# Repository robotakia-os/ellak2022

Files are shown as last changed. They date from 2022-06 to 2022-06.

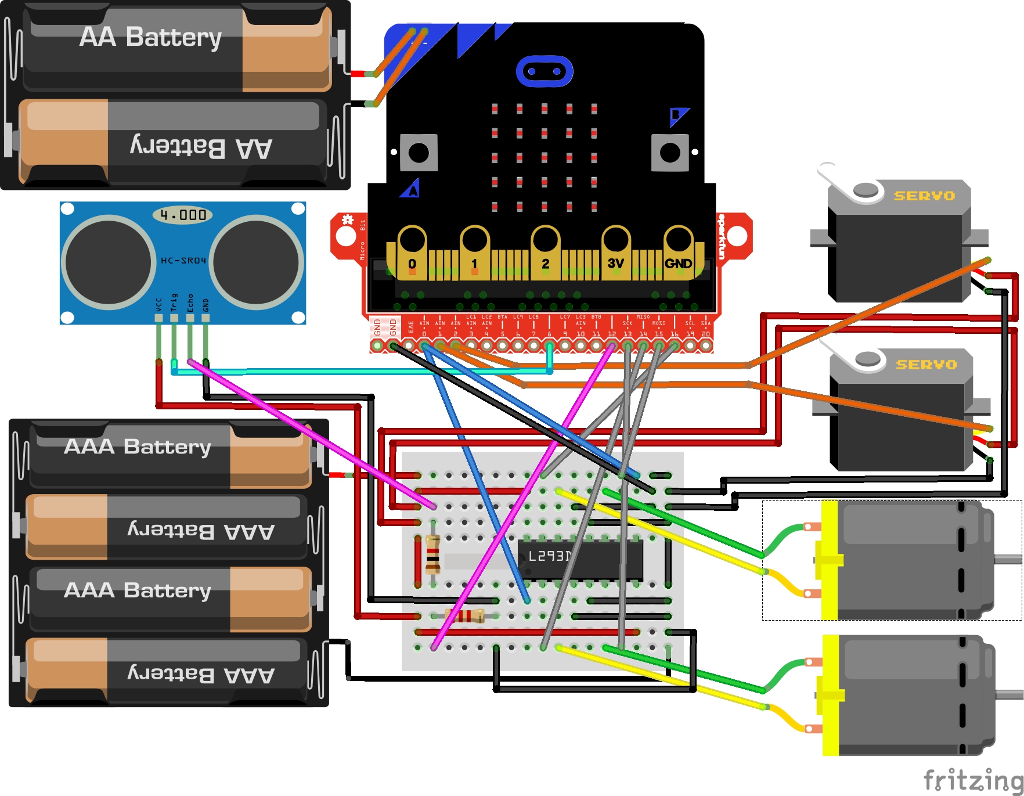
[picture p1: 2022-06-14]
Συνδεσμολογία/robot.jpg

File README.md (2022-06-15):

# ellak2022

4ος Πανελλήνιος Διαγωνισμός Ανοιχτών Τεχνολογιών στην Εκπαίδευση (2022)

Η αλματώδης εξέλιξη της τεχνολογίας τις τελευταίες δεκαετίες έχει αυξήσει τη ζήτηση πολύτιμων μεταλλευμάτων και έχει δημιουργήσει την ανάγκη αξιοποίησης πόρων που παλιότερα έμεναν ανεκμετάλλευτοι. Παρόλα αυτά, η τεχνολογική εξέλιξη της ανθρωπότητας δεν πρέπει να συνοδεύεται από ταυτόχρονη καταστροφή του πλανήτη μας. Η μελλοντική εξόρυξη νέων πόρων και υλικών δεν θα πρέπει να συντελείται σε βάρος των ζώων, των φυτών και των ανθρώπων. Η ζώνη των αστεροειδών αποτελεί μία θεωρητικά ανεξάντλητη πηγή αγαθών που θα μπορούσε δυνητικά να αξιοποιηθεί από την ανθρωπότητα. 

Με την παρούσα εργασία μας, επιχειρήσαμε να αναπαραστήσουμε σε μία μακέτα την προσεδάφιση, την εξερεύνηση και τη συλλογή μεταλλευμάτων από ένα ρομποτικό όχημα σε έναν αστεροειδή. Για τον σκοπό αυτό, δημιουργήσαμε και συναρμολογήσαμε τα μηχανικά μέρη του ρομπότ και υλοποιήσαμε τη συνδεσμολογία των κινητήρων, των αισθητήρων και πλήθος άλλων ηλεκτρονικών εξαρτημάτων. Για την περιήγηση και τον έλεγχο του βραχίονα του ρομπότ χρησιμοποιείται το πληκτρολόγιο του υπολογιστή και η ανίχνευση των πολύτιμων μεταλλευμάτων πραγματοποιείται με τη βοήθεια της Τεχνητής Νοημοσύνης.

Η ιστοσελίδα του έργου: https://openedtech.ellak.gr/robotics2022/robotakia-open-source-na-kitate-pano/

Βίντεο παρουσίασης του έργου: https://www.youtube.com/watch?v=jcSa2XPJCZg

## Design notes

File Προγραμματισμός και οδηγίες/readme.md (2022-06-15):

Το πρόγραμμα robot_program_with_motor_driver είναι παρόμοιο με το robot_program, όμως έχουν τροποποιηθεί τα pin ενεργοποίησης των κινητήρων, για να είναι συμβατό με το Motor Driver Breakout της Waveshare σε περίπτωση που χρησιμοποιηθεί αυτό για την υλοποίηση του κυκλώματος αντί της H-Bridge L293D.

Το αρχείο microbit-mbit-more-v2-0_2_4 είναι απαραίτητο για να προγραμματιστεί το Microbit με τον editor Stretch3 (περισσότερες λεπτομέριες στο pdf "Επεξήγηση προγράμματος").

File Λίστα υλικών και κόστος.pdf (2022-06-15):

- Το συνολικό κόστος υλοποίησης του έργου δεν ξεπερνά τα 60€, συμπεριλαμβανομένων των δευτερευόντων υλικών που χρησιμοποιήθηκαν (σπρέι, μπαταρίες, θερμόκολλα κ.ά.).
- Είτε χρησιμοποιήσουμε για τον έλεγχο των κινητήρων το τσιπάκι H-Bridge L293D (0,6€) είτε την επέκταση Motor Driver Breakout της Waveshare (14,9€) προκύπτει τελικά ένα παραπλήσιο συνολικό κόστος, καθώς μπορεί η σκέτη “γέφυρα” να κοστίζει ελάχιστα, απαιτεί όμως ένα σημαντικό αριθμό περιφερειακών εξαρτημάτων για να υλοποιηθεί το τελικό κύκλωμα.
- Για τον υπολογισμό του κόστους του τυπωμένου ρομπότ προσθέσαμε τα γραμμάρια του PLA που απαιτούνταν για το κάθε κομμάτι. Για τη μάζα του κάθε κομματιού λάβαμε υπόψη την εκτίμηση των γραμμαρίων από το λογισμικό του 3d printer (Prusa Mini). Έτσι προέκυψαν συνολικά 383g και με δεδομένο ότι η τιμή για το 1kg PLA νήματος είναι 20,5€ (τιμή Hellas Digital), προκύπτει ότι το ρομπότ κόστισε περίπου 7,9€ σε PLA.
- Για το χαρτόνι της μακέτας χρησιμοποιήσαμε ένα μεγάλο κομμάτι από κάποια συσκευασία και διαθέταμε ήδη μία απλή USB κάμερα και 3d printer.

Λίστα υλικών και κόστος με H-Bridge L293D

- Νήμα PLA 383g: 7,9€
- Microbit v2: 18,9€
- 2 x Servo Micro: 7,2€
- 2 x DC Gear Motor (με καλώδια): 3,6€
- Μπαταριοθήκη 4xΑΑΑ (με διακόπτη): 1,0€
- Μπαταριοθήκη 2xΑΑΑ (με διακόπτη): 0,9€
- HC-SR04 Ultrasonic sensor: 1,5€
- H-Bridge L293D: 0,6€
- Edge Connector Breakout Board (pre-built): 6,0€
- Mini Breadboard (170 holes): 1,6€
- Καλώδια και αντιστάτες: 2€

Σύνολο: 51,2€

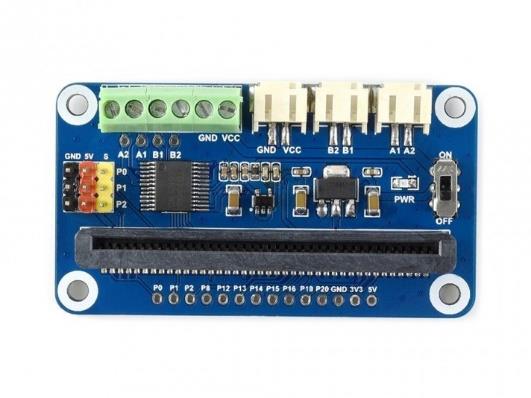
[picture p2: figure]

Λίστα υλικών και κόστος με Motor Driver Breakout

- Νήμα PLA 383g: 7,9€
- Microbit v2: 18,9€
- 2 x Servo Micro: 7,2€
- 2 x DC Gear Motor (με καλώδια): 3,6€
- Μπαταριοθήκη 4xΑΑΑ (με διακόπτη): 1,0€
- Waveshare Motor Driver Breakout: 14,9€
- Pin Header (1x40): 0,1€

Σύνολο: 53,6€

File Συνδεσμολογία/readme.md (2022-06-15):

Για την καταγραφή της συνδεσμολογίας χρησιμοποιήθηκε το λογισμικό Fritzing.

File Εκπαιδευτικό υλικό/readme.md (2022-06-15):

Εκπαιδευτικό υλικό σχετικό με τους αστεροειδείς και τη δυνατότητα εξορύξεων σε αυτούς, με σκοπό την εξοικονόμηση των πόρων και των υλικών του πλανήτη μας.

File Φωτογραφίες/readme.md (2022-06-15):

Φωτογραφίες υψηλής ανάλυσης που λήφθηκαν κατά τη διάρκεια των εργαστηρίων και λεπτομερείς φωτογραφίες του ρομπότ.

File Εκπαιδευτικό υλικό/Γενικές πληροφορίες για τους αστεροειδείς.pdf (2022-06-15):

Γενικές πληροφορίες για τους αστεροειδείς

- Οι αστεροειδείς είναι μικρά σώματα του Ηλιακού συστήματος, που είναι σε τροχιά γύρω από τον Ήλιο. Η συντριπτική πλειονότητα των αστεροειδών είναι συγκεντρωμένη σε δύο Ζώνες: στην Κύρια Ζώνη Αστεροειδών (ανάμεσα στον Άρη και στον Δία) και στη Ζώνη του Κάιπερ (Μεταποσειδώνια Αντικείμενα). Υπολογίζεται ότι υπάρχουν εκατομμύρια αστεροειδείς στο Ηλιακό σύστημα. Το μέγεθός τους ποικίλλει από λίγες δεκάδες μέτρα μέχρι εκατοντάδες χιλιόμετρα. Με πολύ απλά λόγια, μπορούμε να περιγράψουμε τους αστεροειδείς σαν τεράστιους βράχους σε τροχιά γύρω από τον Ήλιο. Κάποιοι από τους αστεροειδείς έχουν και οι ίδιοι μικρούς δορυφόρους, ενώ έχουν ανακαλυφθεί και κάποια τριπλά συστήματα. Οι αστεροειδείς της Κύριας Ζώνης Αστεροειδών θεωρούνται κατάλοιπα από το σχηματισμό του Ηλιακού συστήματος και ήταν το υλικό για έναν μικρό πλανήτη, που όμως δεν σχηματίστηκε ποτέ λόγω της επίδρασης της βαρύτητας του Δία.

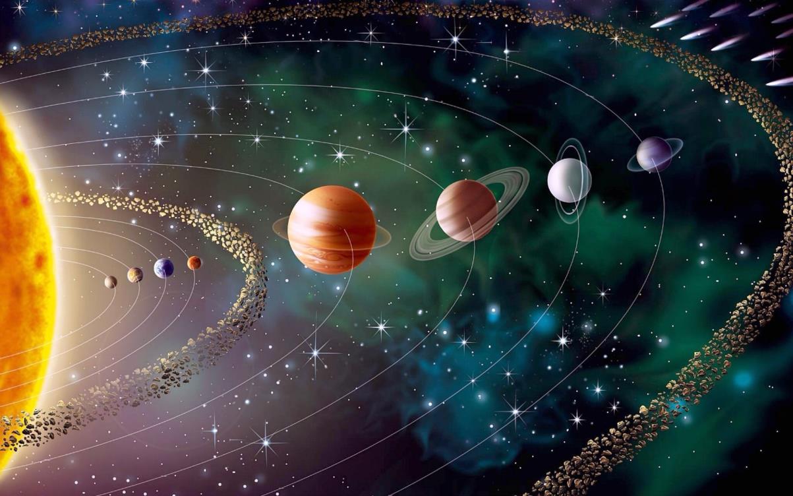
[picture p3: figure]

- Τα σχήματα των αστεροειδών χωρίζονται κυρίως σε δύο οικογένειες. Μερικά είναι σχεδόν απόλυτα σφαιρικά, όπως η Υγεία και η Δήμητρα, ενώ άλλα έχουν περίεργα «μακρόστενα» σχήματα, των οποίων η αδιαμφισβήτητη βασίλισσά τους είναι η Κλεοπάτρα, ο αστεροειδής με σχήμα «κοκκαλοσκύλου». Συνδυάζοντας τα σχήματα των αστεροειδών με πληροφορίες για τις μάζες τους, οι αστρονόμοι διαπίστωσαν ότι οι πυκνότητές τους ποικίλουν. Η μικρότερη πυκνότητα των αστεροειδών, όπως π.χ. των Lamberta και Sylvia, φτάνει στα 1,3 γραμμάρια ανά κυβικό εκατοστό, περίπου όση πυκνότητα του κάρβουνου. Την μεγαλύτερη πυκνότητα έχουν οι αστεροειδείς Ψυχή και Καλλιόπη, 3,9 και 4,4 γραμμάρια ανά κυβικό εκατοστό, αντίστοιχα (συγκριτικά η πυκνότητα του διαμαντιού είναι 3,5 γραμμάρια ανά κυβικό εκατοστό). Αυτές οι μεγάλες διαφορές πυκνότητας δείχνουν ότι η σύνθεση των αστεροειδών ποικίλλει σημαντικά, δίνοντας στους αστρονόμους σημαντικές ενδείξεις για την προέλευσή τους. Συγκεκριμένα, αναδεικνύεται η θεωρία ότι οι λιγότερο πυκνοί αστεροειδείς σχηματίστηκαν σε απομακρυσμένες περιοχές πέρα από την τροχιά του Ποσειδώνα και μετανάστευσαν στη σημερινή τους θέση.
- Μετά το 1990 το ενδιαφέρον για τους αστεροειδείς αναθερμάνθηκε, κυρίως λόγω της ανησυχίας για μια πιθανή σύγκρουση ενός από αυτούς με τη Γη, πράγμα που θα είχε καταστροφικές συνέπειες. Έτσι ξεκίνησε μια προσπάθεια για εντοπισμό, καταγραφή και υπολογισμό της τροχιάς όσο το

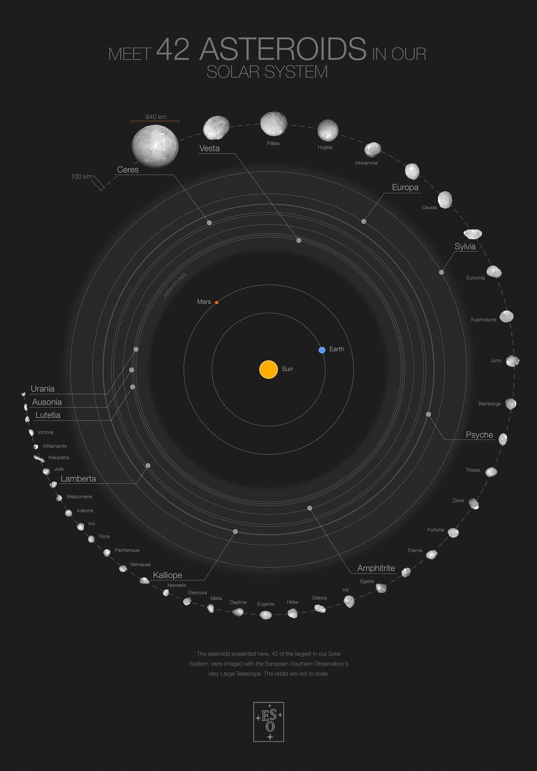
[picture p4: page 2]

δυνατόν περισσότερων αστεροειδών, τόσο με συσκευές σε τροχιά όσο και με γήινα τηλεσκόπια. Η έρευνα αυτή έχει μέχρι στιγμής χαρτογραφήσει εκατοντάδες χιλιάδες αστεροειδείς. Από το 2025 οι αστρονόμοι θα είναι σε θέση να απεικονίσουν περισσότερους αστεροειδείς με λεπτομέρειες με την ολοκλήρωση της κατασκευής του μεγαλύτερου και ισχυρότερου από το τηλεσκοπίου VLT, του τηλεσκοπίου Extremely Large Telescope (ELT).

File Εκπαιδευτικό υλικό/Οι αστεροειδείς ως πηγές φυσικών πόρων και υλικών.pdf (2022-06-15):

Οι αστεροειδείς ως πηγές φυσικών πόρων και υλικών

Μπορεί να ακούγεται σαν επιστημονική φαντασία, αλλά η ιδέα της μετακίνησης βαρέων βιομηχανιών μακριά από τη Γη φαίνεται πολύ λιγότερο παρατραβηγμένη από ποτέ. Η συλλογή πόρων από αστεροειδείς, αντί να χρησιμοποιούμε ό,τι ελάχιστο έχουμε αφήσει στη Γη, θα μπορούσε να είναι το κλειδί για να διασφαλιστεί η επιβίωση των ανθρωπίνων όντων, σύμφωνα με το περιοδικό Discover. Καθώς οι πόροι της Γης μειώνονται, ο πληθυσμός αυξάνεται- και κάτι πρέπει να γίνει. Νέες εταιρίες που έχουν αναπτυχθεί κατά την τελευταία δεκαετία περίπου, προσπαθούν να γίνουν πρωτοπόροι στη συλλογή διαστημικών πόρων. Ακόμα και η NASA επέλεξε πρόσφατα να επενδύσει εκατομμύρια δολάρια σε τεχνολογικές ιδέες που θα μπορούσαν να μας βοηθήσουν να εξερευνήσουμε σεληνιακούς κρατήρες και αστεροειδείς προς εξόρυξη.

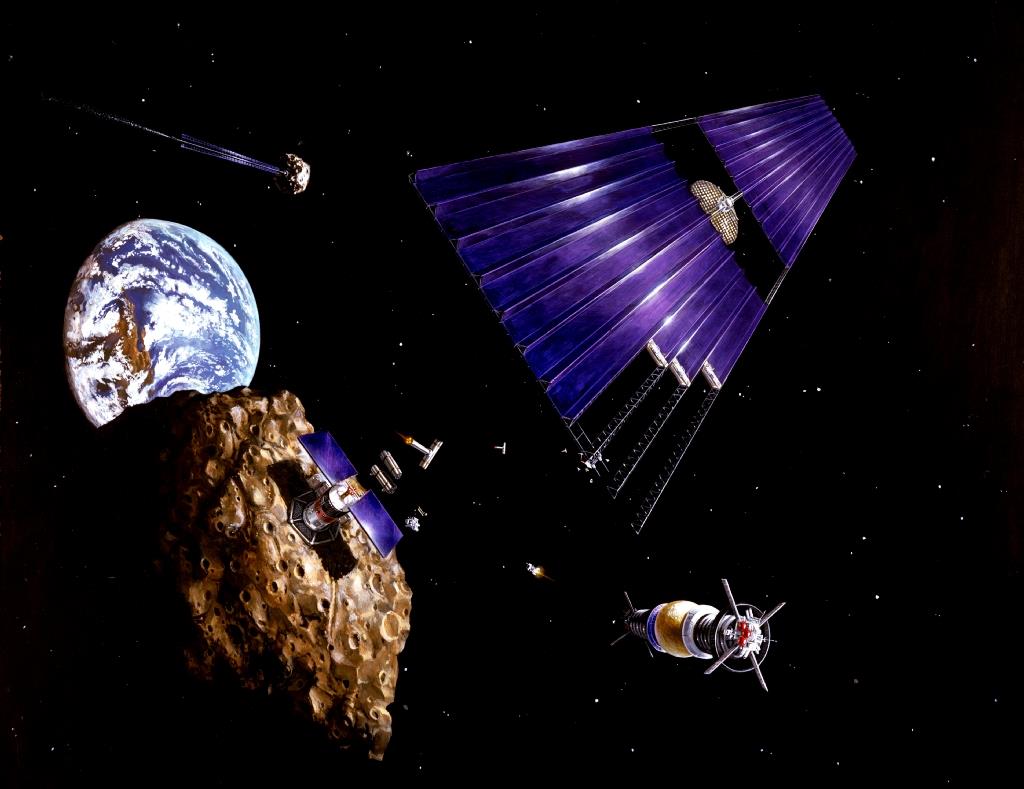
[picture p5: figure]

Τα ουράνια σώματα όπως η Σελήνη και οι αστεροειδείς, περιέχουν χημικά στοιχεία και πολύτιμα μέταλλα, όπως φώσφορο, μόλυβδο, ασήμι, χρυσό, χαλκό και πλατίνα, σε συγκεντρώσεις πολλαπλάσιες των αντίστοιχων μετάλλων που υπάρχουν στο φλοιό της Γης. Τα στοιχεία αυτά μπορούν να χρησιμοποιηθούν για την κατασκευή και τον ανεφοδιασμό των διαστημόπλοιων, αλλά και για την παραγωγή ποικίλων προϊόντων. Έχει επίσης εκτιμηθεί, ότι ένας αστεροειδής διαμέτρου 500 μέτρων ενδέχεται να περιέχει μεγαλύτερη ποσότητα πλατινοειδών από όση έχει εξορυχθεί συνολικά στη διάρκεια της ανθρώπινης ιστορίας.

Αλλά πριν ξεκινήσουμε την εξόρυξη αστεροειδών, πρέπει να καταλάβουμε πού να κοιτάξουμε- και δεν έχουμε διαθέσιμα τηλεσκόπια για να κάνουμε τις κατάλληλες έρευνες, κάτι που συζητήθηκε στο Ευρωπαϊκό Συνέδριο Πλανητικής Επιστήμης στη Ρίγα της Λετονίας το 2017. Το ζήτημα προέκυψε σε ένα συνέδριο του 2016, που ονομάζεται Asteroid Science Intersections with In-Space Mine Engineering (ASIME), το οποίο συγκέντρωσε μηχανικούς και επιστήμονες αστεροειδών για να συζητήσουν τις καλύτερες προσεγγίσεις για την εξόρυξη. «Η εξόρυξη αστεροειδών είναι αυτή η απίστευτη διασταύρωση της επιστήμης, της μηχανικής, της επιχειρηματικότητας και της φαντασίας», δήλωσε ο J.L. Galache, συνιδρυτής και επικεφαλής τεχνολογίας της Aten Engineering. «Το πρόβλημα είναι ότι είναι επίσης ένα κλασικό παράδειγμα ενός σχετικά νεαρού επιστημονικού πεδίου, καθώς όσο περισσότερα μαθαίνουμε για τους αστεροειδείς μέσω αποστολών όπως η Hayabusa και η Rosetta, τόσο περισσότερο συνειδητοποιούμε ότι δεν γνωρίζουμε».

Ενώ υπάρχουν εκατομμύρια από αυτά τα μικρά ουράνια σώματα, τα αντικείμενα που έρχονται πιο κοντά στη Γη (Near Earth Objects, NEO), είναι τα καλύτερα για εξόρυξη καθώς χρειάζεται λίγο καύσιμο ή χρόνος για να φτάσουμε σε αυτούς τους αστεροειδείς. Μέχρι στιγμής, η NASA παρακολουθεί περίπου 16.700 αντικείμενα κοντά στη Γη. Ωστόσο, μόνο λίγα διαστημόπλοια έχουν βρεθεί κοντά σε ένα NEO, επομένως πρέπει να ταξινομήσουμε τους πόρους τους μέσω τηλεσκοπίων. Αυτό είναι δυνατό να γίνει μέσω φασματικών πληροφοριών, οι οποίες δίνουν τη σύνθεση του αστεροειδούς. Σύμφωνα με τον Galache, «Τα NEO ανακαλύπτονται συνήθως όταν είναι στα πιο φωτεινά τους, επομένως η καλύτερη ευκαιρία να τα μελετήσουμε είναι να παρακολουθήσουμε αμέσως τις ανιχνεύσεις με περαιτέρω παρατηρήσεις για να χαρακτηρίσουμε το σχήμα και τις φασματικές τους ιδιότητες». Παρόλα αυτά δεν υπάρχουν ακόμα διαθέσιμα αρκετά καλής ποιότητας, σχετικά μεγάλα, ειδικά τηλεσκόπια για να πραγματοποιηθούν αρκετές αναζητήσεις την κατάλληλη στιγμή. Αρκετοί οργανισμοί και εταιρίες έχουν σχέδια πρώιμου σταδίου για να δουν και να ταξινομήσουν αστεροειδείς χρησιμοποιώντας τηλεσκόπια, συμπεριλαμβανομένων των εταιρειών Deep Space Industries και Planetary Resources και του μη κερδοσκοπικού ιδρύματος B612- αλλά αυτά δεν είναι ακόμη έτοιμα.

Μερικά άλλα προβλήματα που εντόπισε η ομάδα του Galache περιλαμβάνουν την περαιτέρω κατανόηση για το πως συμπεριφέρεται ο ρεγόλιθος στη χαμηλή βαρύτητα ενός αστεροειδούς και για την αφθονία των χημικών στοιχείων σε διαφορετικούς τύπους αστεροειδών στο ηλιακό μας σύστημα. Απαιτείται περισσότερη παρατήρηση επειδή προηγούμενες αποστολές σε αστεροειδείς έδειξαν ότι καθένας από αυτούς που αναλύθηκαν φαινόταν τόσο διαφορετικός. Για παράδειγμα, οι παρατηρήσεις του NEAR Shoemaker στον αστεροειδή Έρως έδειξαν ένα λεπτό στρώμα σκόνης στην επιφάνεια. Αντίθετα, οι παρατηρήσεις του Hayabusa στον αστεροειδή Itokawa αποκάλυψαν συμπαγές έδαφος σε βάθος δεκάδων μέτρων.

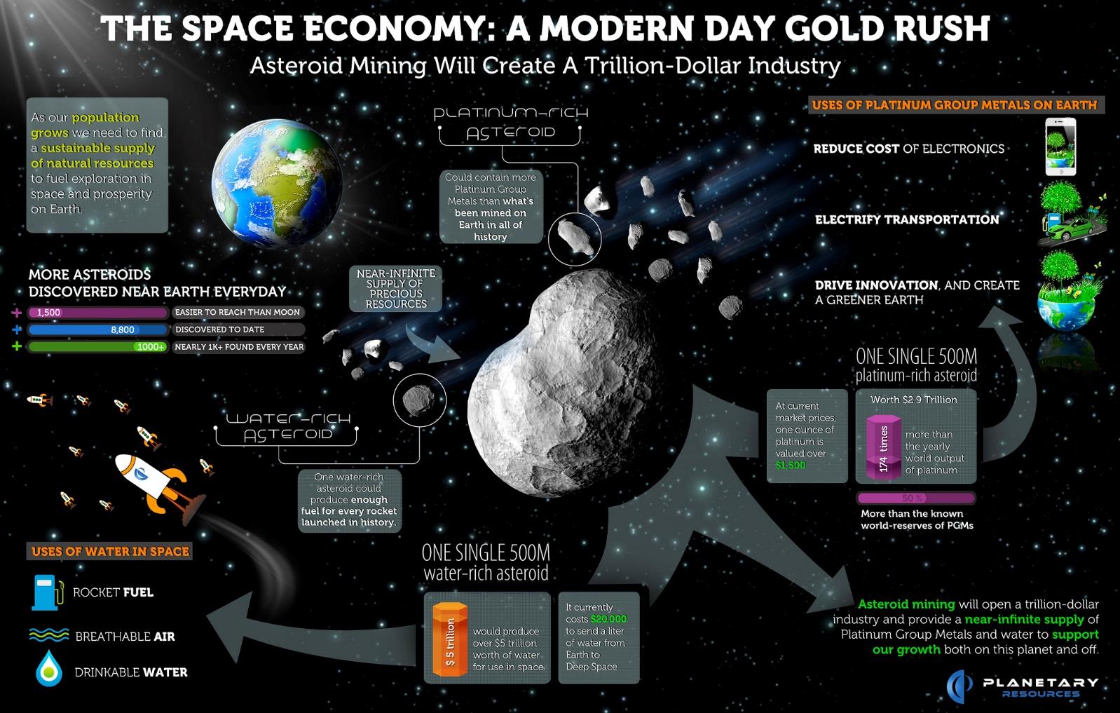
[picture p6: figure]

Όταν στις αρχές του προηγούμενου αιώνα ο πατέρας της θεωρητικής αστροναυτικής Κονσταντίν Τσιολκόφσκυ μιλούσε για πυραυλική προώθηση, τεχνητούς δορυφόρους και διαστημικούς σταθμούς, ποτέ δεν θα μπορούσε να φανταστεί ότι αυτές οι επαναστατικές για την εποχή τους ιδέες θα γίνονταν πραγματικότητα μέσα σε 50 μόλις χρόνια. Η εξόρυξη μεταλλευμάτων από αστεροειδείς είναι ίσως η μόνη από τις προβλέψεις του που δεν έχει ακόμη υλοποιηθεί. Ήδη όμως, αρκετοί επιστήμονες διερευνούν τις πιθανότητες υλοποίησης μιας τέτοιας παράτολμης αποστολής.

Γνωρίζουμε σήμερα ότι οι αστεροειδείς εμπεριέχουν σημαντικές ποσότητες πολύτιμων και σπάνιων μετάλλων. Η μεγάλη περιπέτεια του διαστήματος που ξεκίνησε το 1957 με την εκτόξευση του Σπούτνικ 1 συνεχίζεται. Προς το παρόν όμως, μόνο υποθέσεις μπορούμε να κάνουμε για το πού θα μας οδηγήσει στο μέλλον! Αλλά ο χρόνος εξαντλείται- η κλιματική αλλαγή και οι ταχέως εξαντλούμενοι πόροι μας υποχρεώνουν να κοιτάξουμε πέρα από τον πλανήτη μας. Ας ελπίσουμε ότι θα μπορέσουμε να κάνουμε τη μετάβαση πριν είναι πολύ αργά.

Πηγές:
https://www.fortunegreece.com/https://www.eef.gr/
https://powerpolitics.eu

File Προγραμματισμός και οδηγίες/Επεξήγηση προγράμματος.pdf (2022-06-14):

- Για τον προγραμματισμό χρησιμοποιήθηκε μία εμπλουτισμένη έκδοση της Scratch 3.0 που ονομάζεται Stretch3. Για τον editor επισκεπτόμαστε τη διεύθυνση https://stretch3.github.io/ . Αν χρησιμοποιήσουμε για browser το Firefox θα πρέπει να ενεργοποιηθεί επιπλέον και το Scratch Link (υπάρχει διαθέσιμο στο Microsoft Store), για να είναι εφικτή μέσω Bluetooth η σύνδεση του υπολογιστή με το Microbit. Για τους περιηγητές Chrome και Edge το Scratch Link δεν είναι απαραίτητο.
- Συνδέουμε το καλώδιο του Microbit στον υπολογιστή και “ρίχνουμε” με “drag and drop” στον φάκελο του Microbit που εμφανίζεται το αρχείο microbit-mbit-more-v2-0_2_4.hex , οποιαδήποτε έκδοση του Microbit κι αν έχουμε (v1 ή v2). Στο μήνυμα που περνάει επάνω στα LED του Microbit, μας ζητείται να αλλάξουμε συνεχώς την κλίση του μέχρι να φωτιστούν όλα τα LED που διαθέτει και αν όλα πάνε καλά θα δούμε ένα “M” επάνω στο Microbit. Η τελευταία διαδικασία αρχικοποίησης είναι απαραίτητη μόνο για την πρώτη φορά που θα περάσουμε στο Microbit το αρχείο .hex που προαναφέρθηκε και όχι κάθε φορά που ενεργοποιείται το Microbit.
- Για την υλοποίηση του προγράμματος χρησιμοποιήθηκαν οι επεκτάσεις “Microbit More” και “TM2Scratch” και αυτός είναι ο λόγος που προτιμήθηκε ο editor Stretch3. Η επέκταση “Microbit More” διαθέτει πολλά περισσότερα block συγκριτικά με την τυπική επέκταση “micro:bit” και μπορούμε να εκμεταλλευτούμε καλύτερα τις δυνατότητες του Microbit. Η επέκταση TM2Scratch μας δίνει τη δυνατότητα να χρησιμοποιήσουμε το μοντέλο που δημιουργήσαμε στο Teachable Machine.

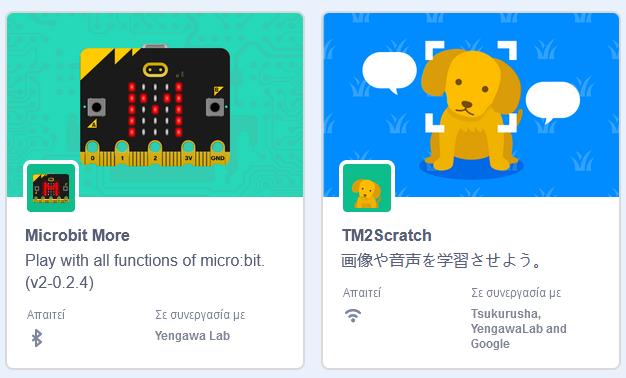
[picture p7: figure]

- Το πρόγραμμα που υλοποιήσαμε διαθέτει το “αντικείμενο” Mineral και τα “υπόβαθρα” Stars και Asteroid. Στην οθόνη που διαθέτει ο editor επιλέξαμε να εμφανίζονται παράμετροι που σχετίζονται με την επιτυχή προσεδάφιση του ρομπότ (πάνω αριστερά), τη θέση του βραχίονα (κάτω αριστερά), τον εντοπισμό μεταλλευμάτων (πάνω δεξιά) και την ταχύτητα του ρομπότ (κάτω δεξιά).

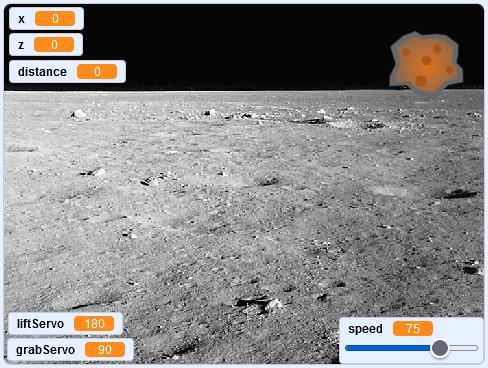
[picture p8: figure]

- Πατώντας το spacebar στο πληκτρολόγιο του υπολογιστή, ενεργοποιούμε αρχικά την κάμερα που διαθέτει το ρομπότ. Επιλέγουμε η εικόνα που λαμβάνουμε να μην είναι “καθρεπτισμένη” για να μπορούμε να χειριστούμε το ρομπότ και από την οθόνη του υπολογιστή χωρίς να έχουμε άμεση επαφή με αυτό. Με τα επόμενα block τοποθετούμε το αντικείμενο Mineral στην κατάλληλη θέση, διπλασιάζουμε το μέγεθός του και ορίζουμε το πόσο θα φαίνεται μέσω του “εφέ φαντάσματος”. Ακολουθούν τα block που σχετίζονται με το Teachable Machine: Δηλώνουμε το link του μοντέλου μας, ορίζουμε ότι η κατηγοριοποίηση θα γίνεται κάθε ένα δευτερόλεπτο και ορίζουμε το κατώφλι ταυτοποίησης στο 60%. Αν επιλέξουμε αρκετά χαμηλό ποσοστό τότε μπορεί να ανιχνεύονται συχνά μεταλλεύματα τα οποία στην πραγματικότητα δεν θα υπάρχουν, ενώ αν επιλέξουμε πολύ υψηλό ποσοστό θα οδηγηθούμε σε πιο σίγουρες αλλά και πιο σπάνιες ταυτοποιήσεις. Κάθε φορά που εντοπίζεται από την κάμερα ένα μετάλλευμα, εμφανίζεται σταδιακά στο επάνω δεξιά μέρος της οθόνης του editor το περιστρεφόμενο αντικείμενο Mineral, ενώ σε περίπτωση που δεν είναι ανιχνεύσιμο κάποιο μετάλλευμα το αντικείμενο Mineral σταδιακά εξαφανίζεται. Τέλος, αν ξαναπατήσουμε το spacebar για δεύτερη φορά τερματίζουμε τη λειτουργία εντοπισμού μεταλλευμάτων και η κάμερα απενεργοποιείται.

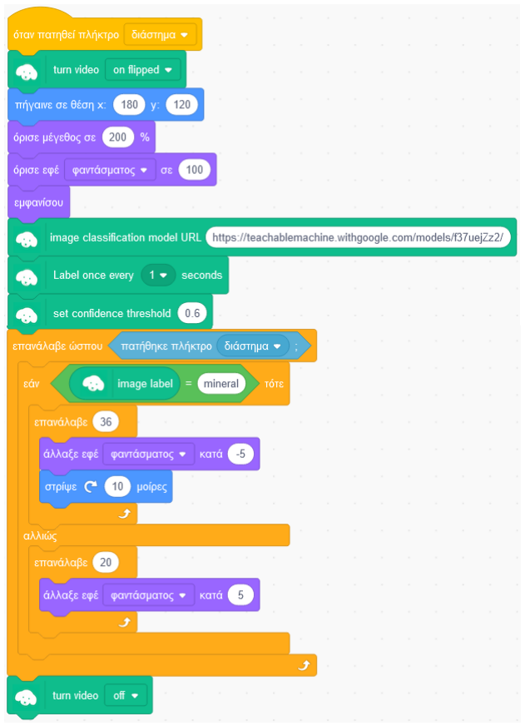
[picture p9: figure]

- Με το πλήκτρο l (landing) ενεργοποιούμε/απενεργοποιούμε το σύστημα επιβεβαίωσης επιτυχούς προσεδάφισης στον αστεροειδή. Όταν χρησιμοποιούμε εντολές που αφορούν κουμπιά του πληκτρολογίου δεν θα πρέπει να ξεχνάμε να ρυθμίζουμε τη γλώσσα του πληκτρολογίου να είναι στα αγγλικά. Στους ακροδέκτες P8 (trig pin) και P12 (echo pin) του Microbit έχει συνδεθεί ο αισθητήρας απόστασης (ultrasonic sensor). Οι εντολές και οι υπολογισμοί που αφορούν τον αισθητήρα σχετίζονται με την αρχή λειτουργίας του. Τα ηχητικά κύματα που αποστέλλονται από τον αισθητήρα ανακλώνται σε κάποιο αντικείμενο και επιστρέφουν στον αισθητήρα, επομένως καλύπτουν διπλάσια απόσταση από αυτή που έχει ο αισθητήρας από το αντικείμενο. Επίσης, η ταχύτητα του ήχου στον αέρα είναι περίπου 343m/s και είναι σταθερή. Τέλος, ο χρόνος που χρειάστηκε ο παλμός για να επιστρέψει στον αισθητήρα καταγράφεται σε μs.
(*) Επομένως: 2d = v(m/s) ∙ t(μs) → 2d = 343(m/s) ∙ (t/1.000.000)(s) → d = 172 ∙ (t/1.000.000) (m) →
→ d = 172 ∙ (t/1.000.000) ∙ 100 (cm) → d = 0,0172 ∙ t (cm) → d = t / 58 (cm)
Στο τέλος του παρακάτω υποπρογράμματος, συνδυάζουμε τις τιμές που καταγράφουμε από τον αισθητήρα απόστασης και από το ενσωματωμένο επιταχυνσιόμετρο του Microbit για τους άξονες x και z (το Microbit τοποθετήθηκε κάθετα στο ρομπότ για εξοικονόμηση χώρου). Αν το ρομπότ βρίσκεται στο έδαφος (distance < 5) και δεν έχει μεγάλη κλίση (x < 300 και z < 300) αυτό σημαίνει ότι έχει προσεδαφιστεί επιτυχώς και στην οθόνη μας φεύγει το υπόβαθρο με τα αστέρια και εμφανίζεται αυτό του αστεροειδούς.

(*) Οι υπολογισμοί προτείνεται να αναφερθούν μόνο σε μαθητές/μαθήτριες που έχουν ολοκληρώσει τη 2

α
Γυμνασίου.

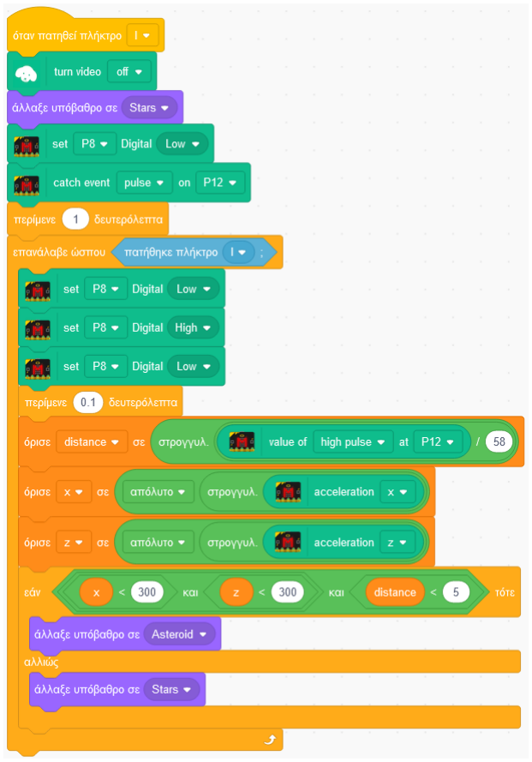
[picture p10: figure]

- Με το πλήκτρο s (start/stop) ενεργοποιούμε/απενεργοποιούμε το σύστημα κίνησης και τον βραχίονα του ρομπότ. Αρχικά ορίζουμε την ταχύτητα του ρομπότ μέσω της μεταβλητής speed στο 75%. Στη συνέχεια δίνουμε αρχικές τιμές στις μεταβλητές που σχετίζονται με τον βραχίονα και ενεργοποιούμε τα servo του μέσω των ακροδεκτών P1 και P2 ώστε να βρεθεί σε κατακόρυφη θέση και κλειστός. Θα κινούμε το ρομπότ με τα βελάκια του πληκτρολογίου και τον βραχίονα με τα κουμπιά u (up), d (down), o (open) και c (close).

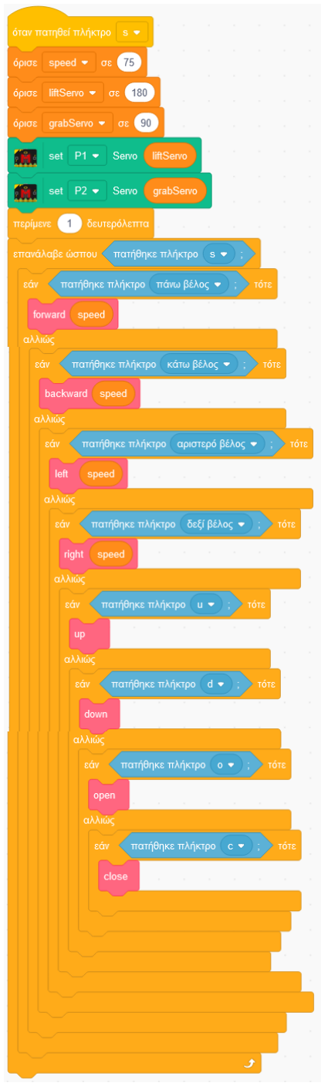
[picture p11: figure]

- Για το παραπάνω υποπρόγραμμα δημιουργήσαμε 8 δικά μας block. Τα block που σχετίζονται με την κίνηση του ρομπότ είναι τα forward, backward, left και right και δέχονται σαν παράμετρο τη μεταβλητή speed. Επειδή τόσο η θέση των servo όσο και η ταχύτητα περιστροφής των κινητήρων καθορίζονται από την PWM (διαμόρφωση πλάτους παλμού) που εκτελεί ο μικροελεγκτής, επιλέγουμε να ξανατοποθετήσουμε τις εντολές για τα servo στην αρχή για να αποφύγουμε το τρεμόπαιγμα του βραχίονα κάθε φορά που κινούμε το ρομπότ. Για τον έλεγχο της ταχύτητας περιστροφής των κινητήρων χρησιμοποιούμε τον ακροδέκτη P0 του Microbit στον οποίο έχουμε συνδέσει τα 2 καλώδια που καταλήγουν στους ακροδέκτες της H-Bridge L293D που καθορίζουν την ταχύτητα μέσω PWM. Οι ακροδέκτες P13, P14, P15 και P16 δέχονται 0V ή 3,3V (Low ή High) και συνδέονται στους αντίστοιχους ακροδέκτες της “γέφυρας” που καθορίζουν τη φορά περιστροφής των κινητήρων.

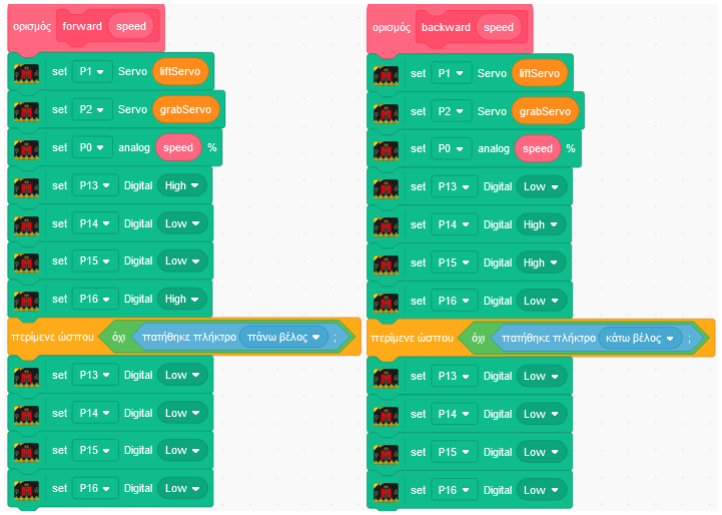
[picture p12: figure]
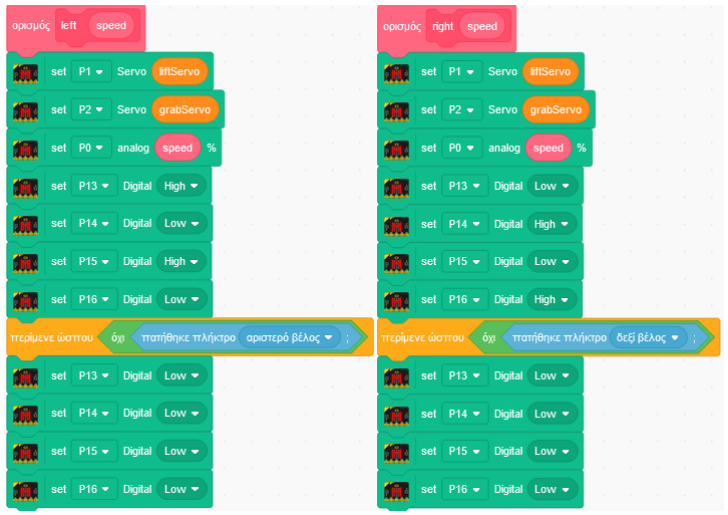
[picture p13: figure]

- Τα block που σχετίζονται με την περιστροφή των servo είναι τα up, down, open και close. Η μεταβλητή liftServo καθορίζει τη θέση του servo που ανεβοκατεβάζει τον βραχίονα και το εύρος των μοιρών στις οποίες μπορεί να περιστρέφεται είναι από 60ο

έως 180ο
. Η μεταβλητή grabServo καθορίζει τη θέση του servo που ανοιγοκλείνει τον βραχίονα και το εύρος των μοιρών στις οποίες μπορεί να περιστρέφεται είναι από 0ο έως
90

ο

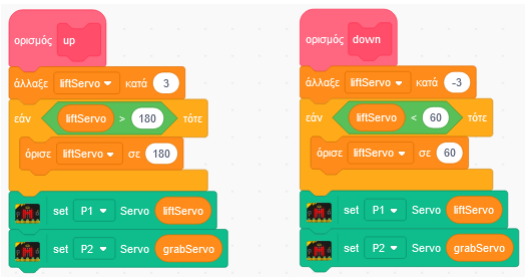
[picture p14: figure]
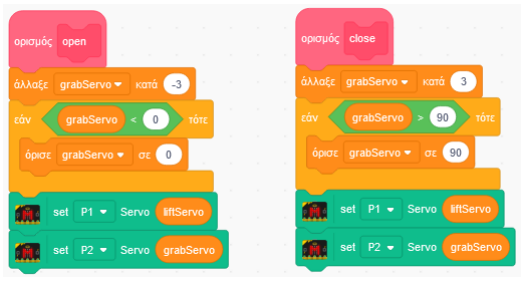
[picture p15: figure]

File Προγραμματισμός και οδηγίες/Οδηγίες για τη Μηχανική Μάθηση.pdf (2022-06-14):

- Για να “εκπαιδεύσουμε” τον υπολογιστή να αναγνωρίζει τα επιθυμητά αντικείμενα χρησιμοποιήσαμε τη Μηχανική Μάθηση (υποκατηγορία της Τεχνητής Νοημοσύνης) μέσω της πλατφόρμας Teachable Machine. Πρόκειται για μία εύχρηστη πλατφόρμα με την οποία μπορεί να παραχθεί και να εξαχθεί ένα μοντέλο με πολύ απλό τρόπο μέσα σε λίγα βήματα.
- Ανοίγουμε την ιστοσελίδα https://teachablemachine.withgoogle.com/train και επιλέγουμε “Image Project”.

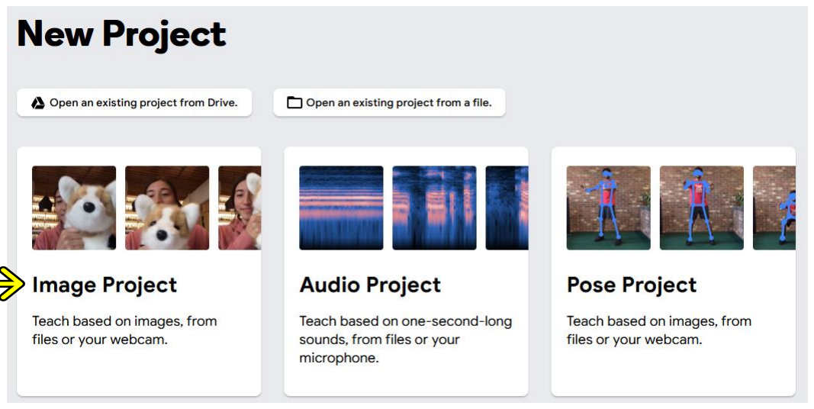
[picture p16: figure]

- Στη συνέχεια επιλέγουμε “Standard image model”.

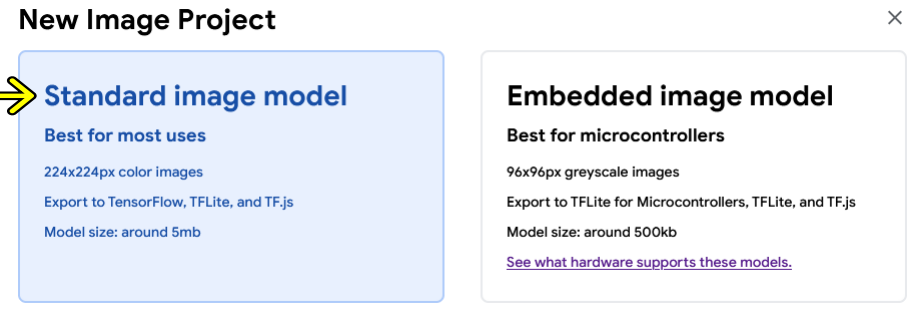
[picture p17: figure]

- Αρχικά δίνουμε στις κλάσεις τα ονόματα “mineral” και “nothing”. Για να προσθέσουμε παραδείγματα εικόνων στην κάθε κλάση πατάμε “Webcam” και στη συνέχεια αποδεχόμαστε τη χρήση της κάμερας από τον ιστότοπο. Κρατώντας πατημένη την ένδειξη “Hold to Record” παίρνουμε περίπου 500 δείγματα για κάθε κλάση ώστε να προκύψει ένα σχετικά αξιόπιστο μοντέλο. Στη συνέχεια πατάμε “Train Model” και περιμένουμε 2-3 λεπτά για να ολοκληρωθεί το “Training”.

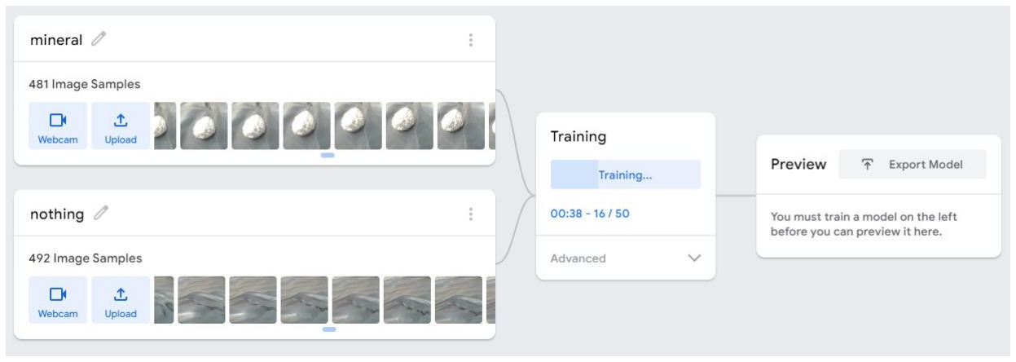
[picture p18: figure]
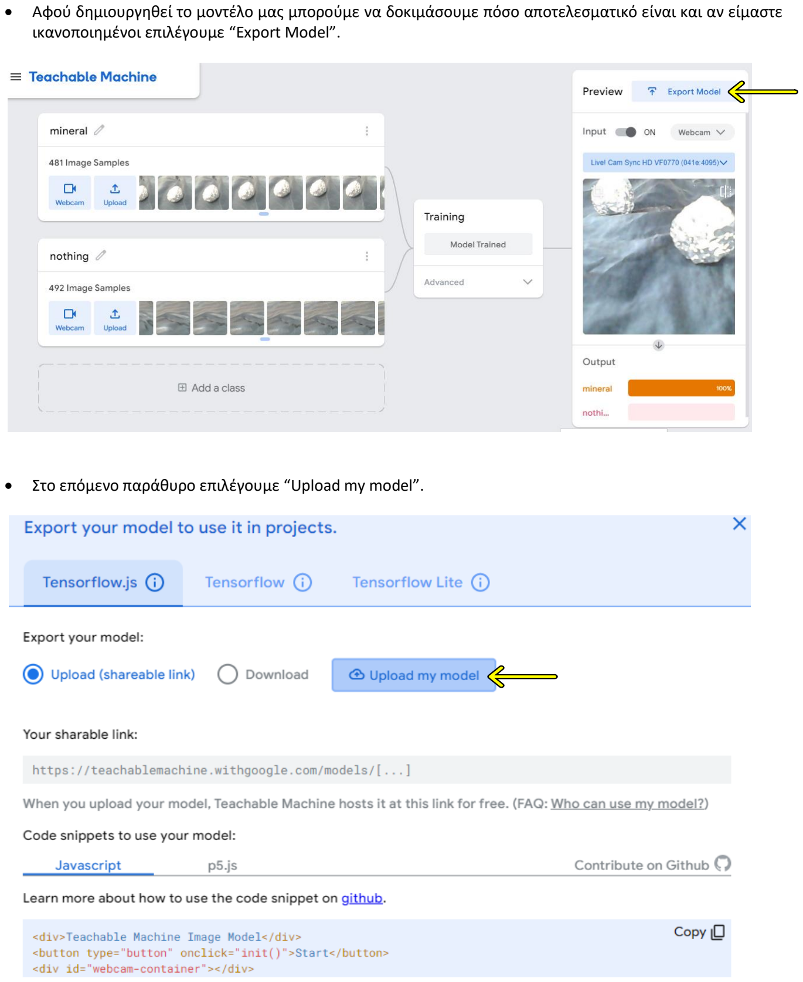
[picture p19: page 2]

- Αφού δημιουργηθεί το μοντέλο μας μπορούμε να δοκιμάσουμε πόσο αποτελεσματικό είναι και αν είμαστε ικανοποιημένοι επιλέγουμε “Export Model”.
- Στο επόμενο παράθυρο επιλέγουμε “Upload my model”.

- Όταν ολοκληρωθεί το uploading, αντιγράφουμε το link που μας παρουσιάζεται για να το προσθέσουμε αργότερα στο πρόγραμμα. Εδώ είναι το https://teachablemachine.withgoogle.com/models/f37uejZz2/ .

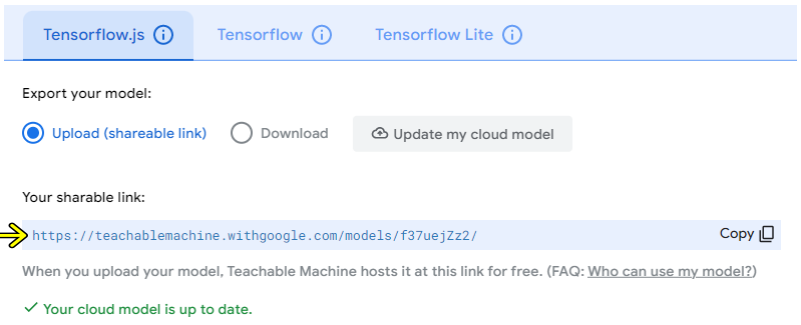
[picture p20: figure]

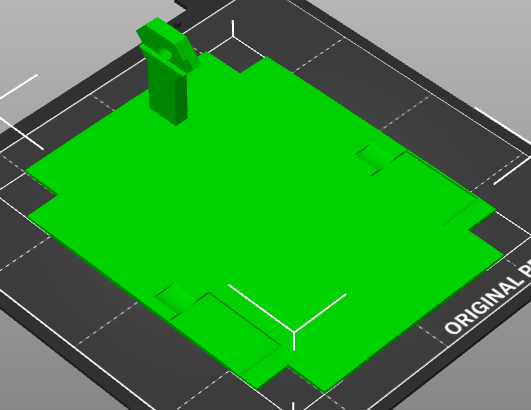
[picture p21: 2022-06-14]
3D printing/Εικόνες/chassis.png

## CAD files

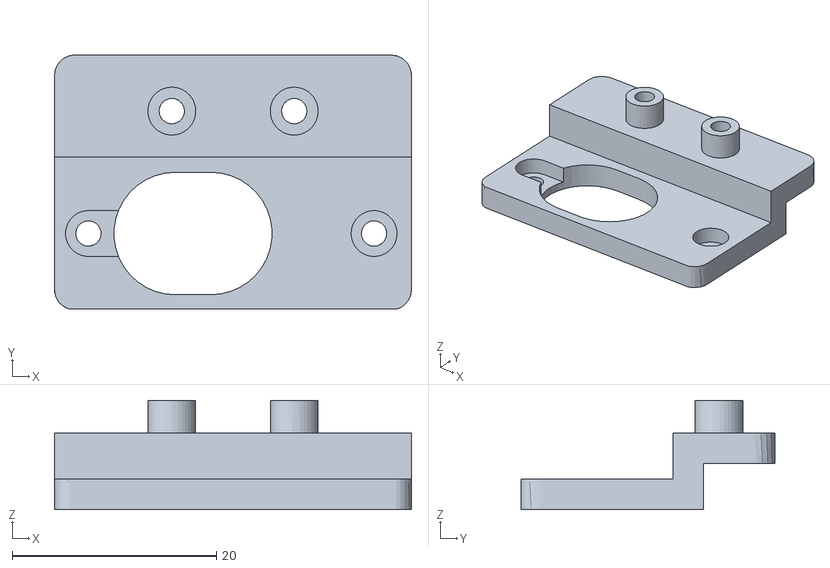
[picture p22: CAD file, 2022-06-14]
3D printing/Αρχεία stl/arm1.stl
35.0 x 24.9 x 10.7

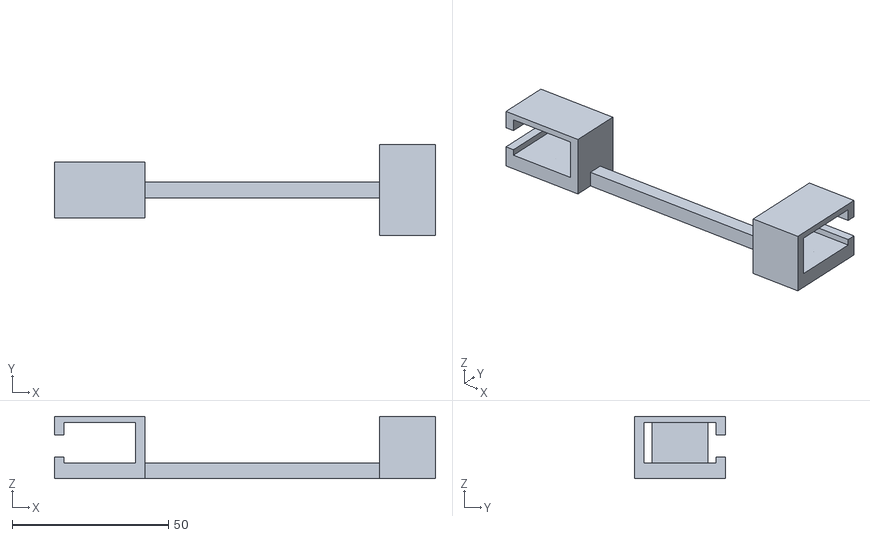
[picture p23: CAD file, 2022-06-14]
3D printing/Αρχεία stl/arm3.stl
122.0 x 29.0 x 20.0

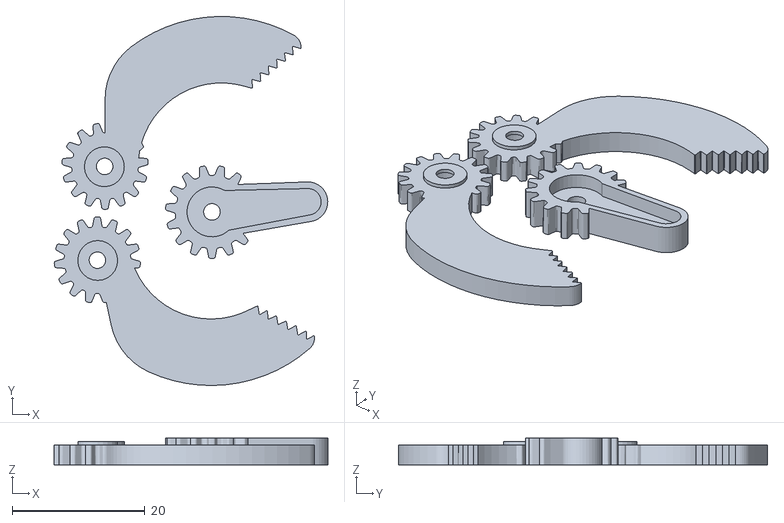
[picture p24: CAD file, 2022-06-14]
3D printing/Αρχεία stl/arm2.stl
41.1 x 55.5 x 4.00

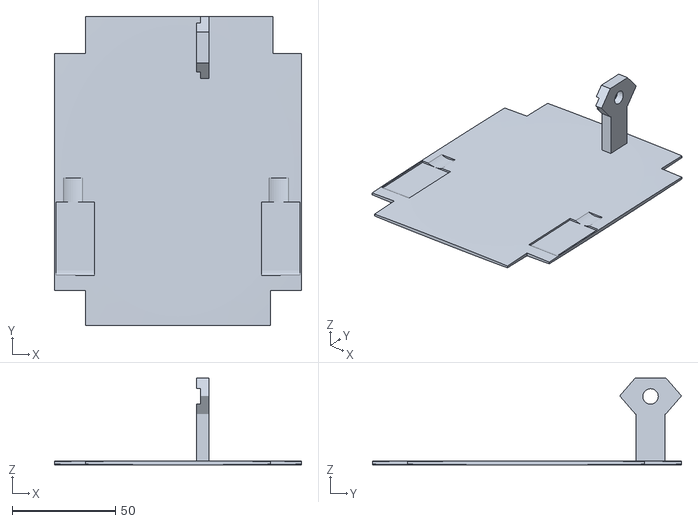
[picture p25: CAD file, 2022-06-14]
3D printing/Αρχεία stl/chassis.stl
120.0 x 150.0 x 42.2

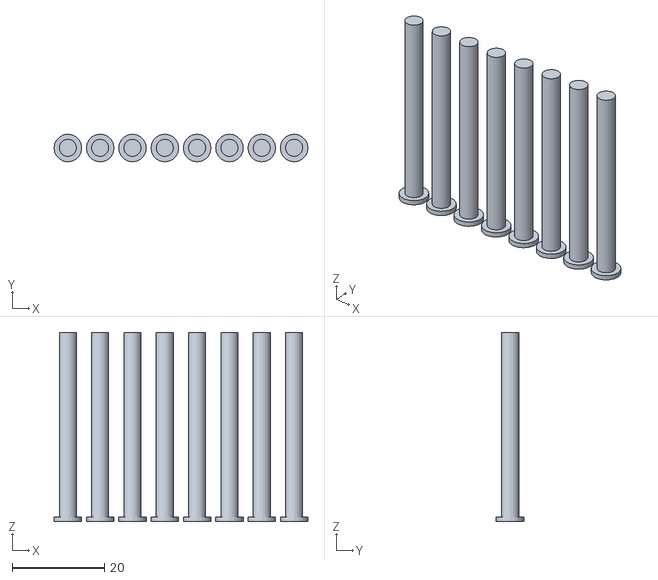
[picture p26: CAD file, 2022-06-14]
3D printing/Αρχεία stl/wheel_pin.stl
55.0 x 6.00 x 41.0

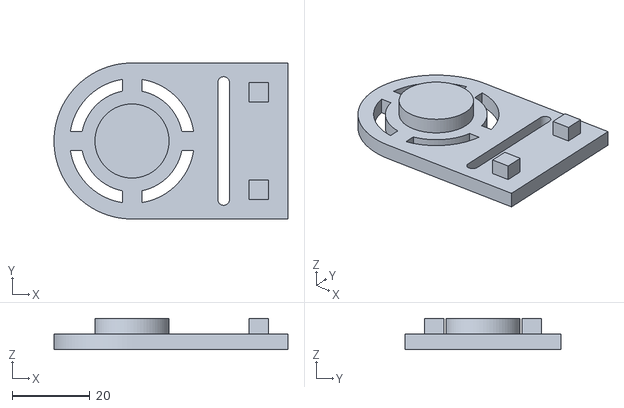
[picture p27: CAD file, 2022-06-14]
3D printing/Αρχεία stl/cog_bracket_outer.stl
60.0 x 40.0 x 8.00

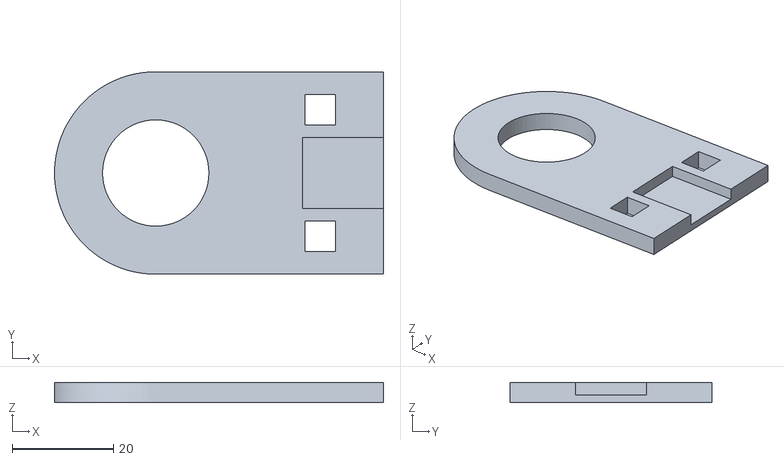
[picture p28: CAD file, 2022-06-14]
3D printing/Αρχεία stl/cog_bracket_inner.stl
65.0 x 40.0 x 4.00

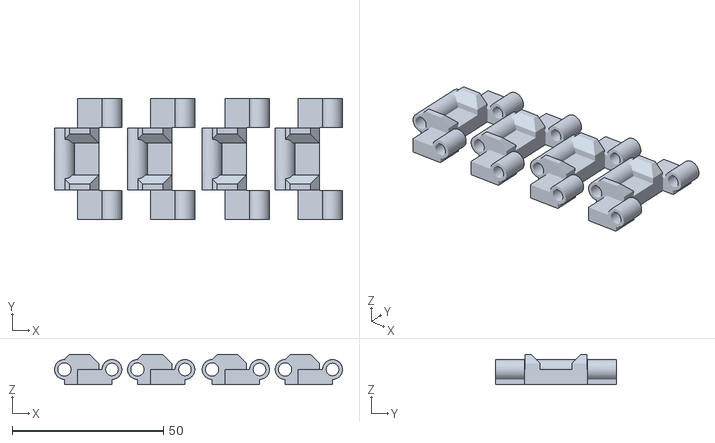
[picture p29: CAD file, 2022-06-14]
3D printing/Αρχεία stl/track.stl
95.3 x 40.0 x 10.0

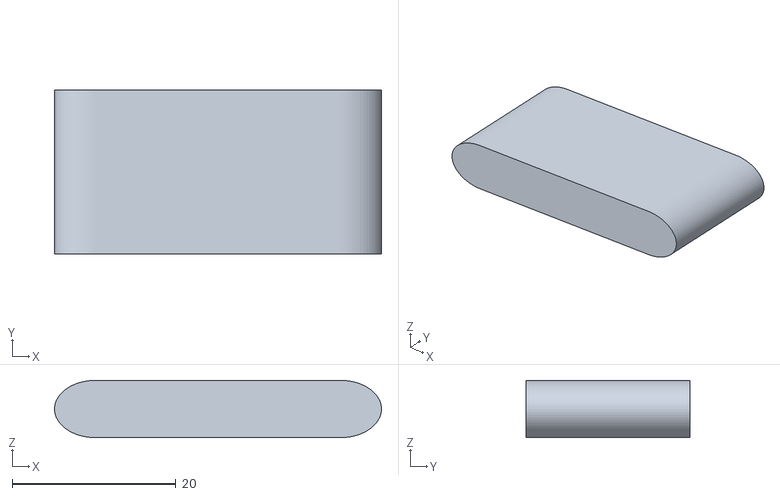
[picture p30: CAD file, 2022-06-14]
3D printing/Αρχεία stl/support.stl
40.0 x 20.0 x 7.00

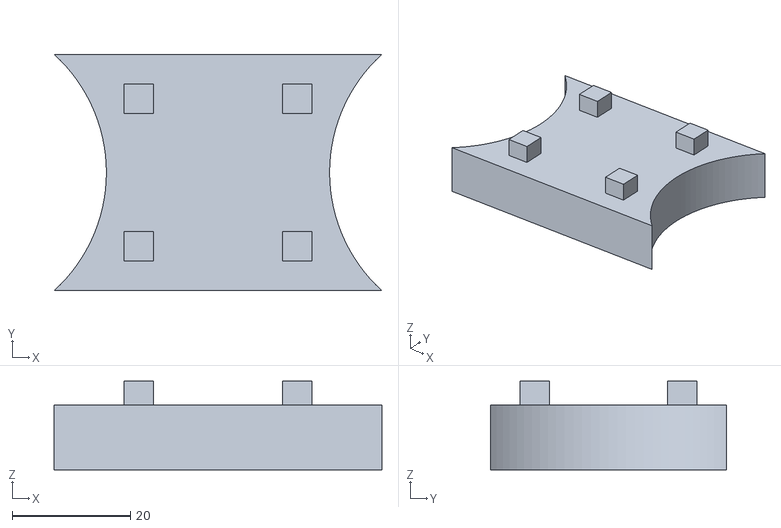
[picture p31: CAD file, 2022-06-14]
3D printing/Αρχεία stl/track_mid_frame.stl
55.5 x 40.0 x 15.0

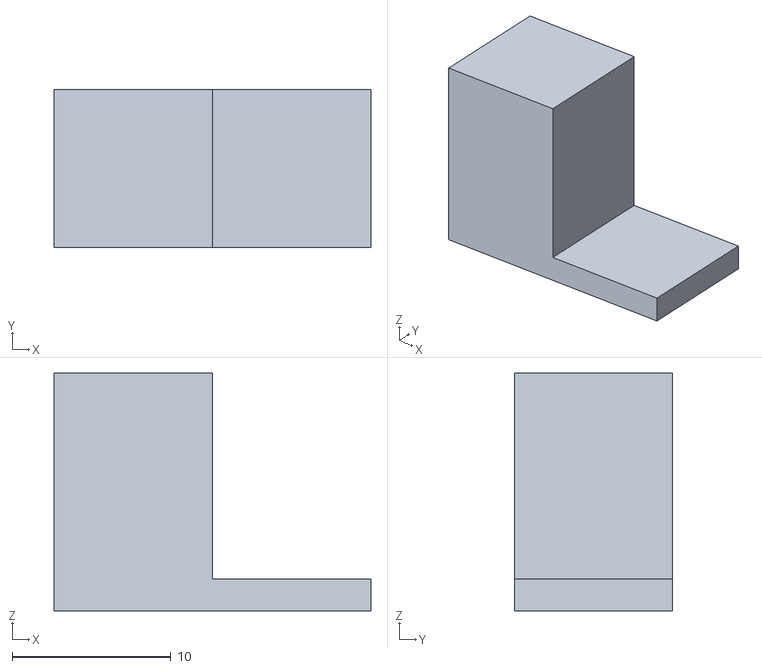
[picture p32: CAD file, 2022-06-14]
3D printing/Αρχεία stl/ultrasonic_base.stl
20.0 x 10.0 x 15.0

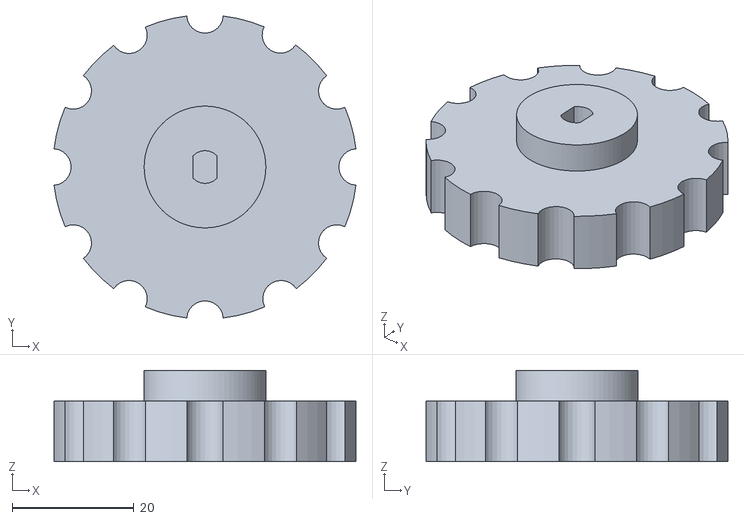
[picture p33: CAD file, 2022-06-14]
3D printing/Αρχεία stl/cog.stl
49.6 x 49.6 x 15.0

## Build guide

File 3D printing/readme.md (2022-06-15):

Τα αρχεία stl σχεδιάστηκαν στην πλατφόρμα Tinkercad. Τα αρχεία gcode παράχθηκαν από το λογισμικό του εκτυπωτή Prusa Mini. Για τη δημιουργία των ερπυστριών τροποποιήσαμε σχέδια που βρήκαμε στην ιστοσελίδα https://www.thingiverse.com/thing:652851 .

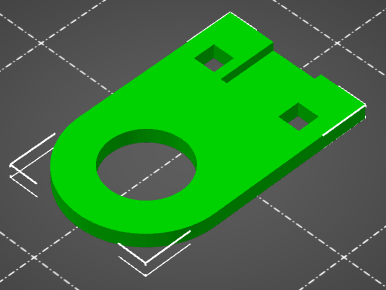
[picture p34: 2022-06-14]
3D printing/Εικόνες/cog_bracket_inner.png

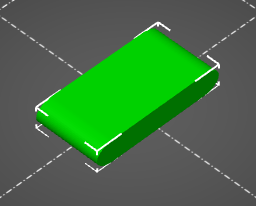
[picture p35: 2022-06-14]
3D printing/Εικόνες/support.png

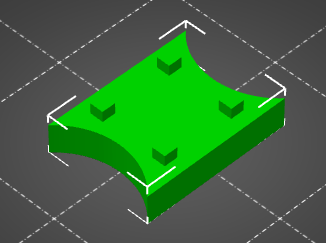
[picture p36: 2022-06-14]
3D printing/Εικόνες/track_mid_frame.png

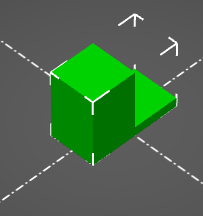
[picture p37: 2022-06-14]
3D printing/Εικόνες/ultrasonic_base.png
